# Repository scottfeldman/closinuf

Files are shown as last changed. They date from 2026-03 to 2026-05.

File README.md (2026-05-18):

# closinuf

**3D point scanner** — live 3D coordinates from four quadrature encoders on a Raspberry Pi, with a small web UI, foot‑switch capture, and FreeCAD‑friendly export.

<p align="center">
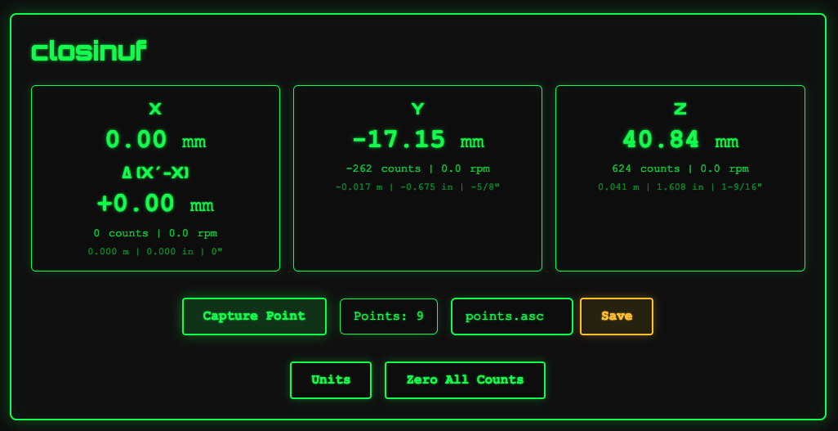
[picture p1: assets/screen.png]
closinuf 3D point scanner UI
  
</p>

## What it does

- Tracks **X**, **X'**, **Y**, **Z** from dedicated rotary encoders.  
- **Capture Point** in the browser or a **GPIO foot switch** appends the current **(X, Y, Z)** to a list (mm internally).
- **Save** downloads an **ASC** point cloud file, which can be imported into FreeCAD as a point cloud. 
- **Units** cycles mm → m → in → ft. **Zero** clears counts and points.
- **Short beep** on capture when audio output is available (speakers or HDMI).

## Hardware

See [HARDWARE.md](HARDWARE.md).

## Install on the Pi (`install.sh`)

1. On the Pi, clone the repository and enter the project directory:

   ```bash
   git clone https://github.com/scottfeldman/closinuf.git
   cd closinuf
   ```

2. Run the install script as root:

   ```bash
   sudo ./install.sh
   ```

3. Reboot if the installer prompts you to. 

What the script does:

- Enables **SPI** and relocates kernel CE pins off GPIO 8/7 (`dtoverlay=spi0-2cs,cs0_pin=12,cs1_pin=13`) in `/boot/firmware/config.txt`.
- Installs **`alsa-utils`** (`aplay` for capture beep) and **`golang-go`** if `go` is missing.
- Builds **`./closinuf`** in the repo.
- Adds the install user to **`spi`** and **`gpio`** groups (for local `go build` / debugging without the service).
- Installs **closinuf** **systemd** services: **`closinuf.service`** (app on :3000, runs as **root** for `/dev/mem` GPCLK, SPI, and GPIO), **`closinuf-browser.service`** (Chromium as install user)
- Prompts to **reboot** when SPI settings were added to `config.txt` (first install)

Useful commands:

```bash
sudo systemctl status closinuf closinuf-browser
sudo journalctl -u closinuf -f
```

## Manual run (development)

```bash
go build -o closinuf .
sudo ./closinuf
```

Open `http://127.0.0.1:3000`. Root is required for GPCLK setup (`/dev/mem`); the systemd service runs as root for the same reason.

## ASC export

One point per line: `X Y Z` in **millimeters** (space‑separated), suitable for FreeCAD point cloud import.

## Stack

Fiber, HTMX, gomponents, **LS7366R** counters over **SPI0**, **go-gpiocdev** (chip selects + foot switch).

## License

MIT — see [LICENSE](LICENSE).

## Author

Scott Feldman (2026)

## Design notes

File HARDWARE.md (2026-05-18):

# closinuf — Hardware Design

This document captures the **encoder counter board** that sits between the four
quadrature encoders and the Raspberry Pi. The board is a **Raspberry Pi 4 HAT**:
it stacks directly onto the Pi's 40‑pin GPIO header via `J1` and takes all of
its power from that header (3.3 V and 5 V). Counting is done in hardware by four
**LS7366R** single‑channel 32‑bit quadrature counter ICs (one encoder each), read by the Pi over **SPI0**.

The PCB sources for this design live in [`pcb/`](pcb/). This file is the
canonical reference for the schematic; if the two ever disagree, treat this
document as the spec.

---

## 1. System overview

```
                                                  +3.3V
                                                    │
                                                    ▼
   ┌──────────────┐   SPI0 + GPCLK0           ┌──────────────┐
   │              │   MOSI/MISO/SCLK ──┬─────►│ LS7366R  U1  │── Encoder X
   │   Raspberry  │   SS/ per chip      │      └──────────────┘
   │     Pi       │                     │      ┌──────────────┐
   │              │   GPIO4 (GPCLK0) ───┼─────►│ LS7366R  U2  │── Encoder X′
   │              │   (pin 7) ─ fCKi    │      └──────────────┘
   │              │   all four ICs       │      ┌──────────────┐
   │              │                     ├─────►│ LS7366R  U3  │── Encoder Y
   │              │                     │      └──────────────┘
   │              │                     │      ┌──────────────┐
   │              │                     └─────►│ LS7366R  U4  │── Encoder Z
   │  GPIO 26 ◄───┼── foot switch               └──────────────┘
   └──────────────┘
```

Four ICs total (one quadrature counter each). The Pi drives a shared **filter
clock** into every chip’s **fCKi** from **GPCLK0 on GPIO4** (header pin 7), and
periodically selects a chip, issues `READ_CNTR`, and reads four counter bytes
(32‑bit mode, `MDR1 = 0x00`).

### Counter range

Firmware uses **32‑bit** counter mode (`MDR1 = 0x00`). Signed headroom is
2^31 counts — far more than this application needs (600 PPR × 4 → 2400
counts/rev on a 50 mm wheel).

---

## 2. Bill of materials

| Ref | Qty | Part | Suggested MPN | KiCad footprint | Notes |
|---|-----|---|---|---|---|
| U1–U4 | 4 | **LS7366‑R** (DIP‑14, through‑hole) | `LS7366-R` | `LS7366R:DIP762W45P254L1917H533Q14` | Single‑channel 32‑bit quadrature counter with SPI (DIP package used on this board). |
| C1–C4 | 4 | 0.1 µF, X8R, disc, 50 V, ±10 % | TDK `FA18X8R1E104KNU00` | `Capacitor_THT:C_Disc_D3.8mm_W2.6mm_P2.50mm` | Decoupling, **at pin 14 (VDD)** of each chip. |
| C5 | 1 | 10 µF, X7R, disc, 10 V, ±10 % | TDK `FG14X7R1A106KRT00` | `Capacitor_THT:C_Disc_D5.0mm_W2.5mm_P2.50mm` | Bulk on the 3.3 V rail. |
| RN1–RN4 | 4 | 3× 4.7 kΩ bussed resistor network (SIP‑4) | Bourns `4604X-101-472LF` | `Resistor_THT:R_Array_SIP4` | Pull‑ups on every encoder A and B, plus the foot‑switch pull‑up. |
| J1 | 1 | 2×20 0.1″ socket | Samtec `SSW-120-01-T-D` (or any 2×20 2.54 mm socket) | `Connector_PinSocket_2.54mm:PinSocket_2x20_P2.54mm_Vertical` | Pi GPIO header connector. |
| J6 | 1 | 4‑pos PCB terminal block, 5 mm pitch, horizontal entry | Phoenix Contact `PT 1,5/ 4-5,0-H` (1935284) | `TerminalBlock_Phoenix:TerminalBlock_Phoenix_PT-1,5-4-5.0-H_1x04_P5.00mm_Horizontal` | Foot switch — only 2 of the 4 positions are wired (GPIO 26 + GND). |
| J2–J5 | 4 | 4‑pos PCB terminal block, 5 mm pitch, horizontal entry | Phoenix Contact `PT 1,5/ 4-5,0-H` (1935284) | `TerminalBlock_Phoenix:TerminalBlock_Phoenix_PT-1,5-4-5.0-H_1x04_P5.00mm_Horizontal` | Encoder cables (X, X′, Y, Z). Each carries A, B, **+5 V**, GND. |

---

## 3. Raspberry Pi pin assignment

40‑pin header. Only the pins relevant to this board are listed.

| Function | RPi GPIO (BCM) | Header pin |
|---|---|---:|
| SPI0 MOSI | GPIO 10 | 19 |
| SPI0 MISO | GPIO 9 | 21 |
| SPI0 SCLK | GPIO 11 | 23 |
| SS/ → U1 (encoder X) | GPIO 8 (CE0) | 24 |
| SS/ → U2 (encoder X′) | GPIO 7 (CE1) | 26 |
| SS/ → U3 (encoder Y) | GPIO 5 | 29 |
| SS/ → U4 (encoder Z) | GPIO 6 | 31 |
| **GPCLK0** → all **fCKi** | GPIO 4 | 7 |
| **Foot switch** (`J6`) | GPIO 26 | 37 |
| 3.3 V supply (LS7366R VDD) | — | 1, 17 |
| 5 V supply (encoder modules) | — | 2, 4 |
| GND | — | 6, 9, 14, 20, 25, 30, 34, 39 |

Notes:

- SPI1 is **not used**. All four LS7366R devices share **SPI0** MOSI, MISO, and
  SCLK; only **SS/** is unique per chip. Linux exposes **CE0** and **CE1** as
  GPIO 8 and 7; **U3** and **U4** use GPIO 5 and 6 as **manual** chip selects
  (drive high when idle, assert low during a transfer for that IC only).
- **Filter clock:** Tie **fCKi** (pin 2) on **U1–U4** together and connect to
  **GPIO4 / GPCLK0** (header pin 7). Configure the Pi to output a continuous
  square wave in the MHz range (see below). Per the datasheet, the internal
  filter clock `f_f` must satisfy `f_f >= 4 * f_QA`, where `f_QA` is the
  maximum frequency on encoder **A** in quadrature mode; at 3.3 V, `f_QA` is
  rated up to **4.5 MHz**, so **~9 MHz** (or higher) GPCLK is a comfortable
  choice.
- LS7366R devices, the pull‑up resistors, and the foot‑switch network all run
  from the Pi's **3.3 V** rail (header pins 1 / 17). The four encoder modules
  run from the Pi's **5 V** rail (header pins 2 / 4); their open‑collector
  A/B outputs are pulled up to 3.3 V at the LS7366R end so signal levels stay
  inside the chip's input range. Four LS7366Rs plus the pull‑ups still keep
  3.3 V load modest; encoder current is dominated by the encoder modules
  themselves (typically tens of mA each — check your encoder spec).

### `/boot/firmware/config.txt`

```ini
dtparam=spi=on
dtoverlay=spi0-2cs,cs0_pin=12,cs1_pin=13
```

`spi0-2cs` with **`cs0_pin` / `cs1_pin` moved off GPIO 8 and 7** is required: the
board uses those pins for manual **SS/** to the LS7366Rs. `install.sh` adds these
lines automatically.

Reboot after editing; `config.txt` is read only at boot. Verify with `ls /dev/spidev*`.

**GPCLK on GPIO4 (pin 7):** On **Raspberry Pi 4 (BCM2711)**, closinuf programs
GPCLK0 at **~9 MHz** from the **19.2 MHz oscillator** via `/dev/mem` in
`gpclk.go` at startup. The **`closinuf.service`** unit runs the app as
**root** so register access works without a separate setup script.

See [GPCLK / pinout](https://pinout.xyz/pinout/gpclk) and the LS7366R `fCKi`
filter requirements above.

On startup, `journalctl -u closinuf` should log `GPCLK0_CTL=… GPCLK0_DIV=0x00002222`.
Confirm ~9 MHz on header pin 7 with a scope if counts stay at zero.

---

## 4. LS7366R wiring (per chip)

Pinout (DIP‑14 / SOIC‑14, top view — per LSI/CSI datasheet):

```
                 LS7366R
               ┌────────────┐
      fCKO   1 ┤            ├ 14   VDD
      fCKi   2 ┤            ├ 13   CNT_EN
       VSS   3 ┤            ├ 12   A
       SS/   4 ┤            ├ 11   B
       SCK   5 ┤            ├ 10   INDEX/
      MISO   6 ┤            ├  9   DFLAG/
      MOSI   7 ┤            ├  8   LFLAG/
               └────────────┘
```

Wiring is **identical** for U1–U4 except **SS/** and which encoder A/B pair
connects to pins 12 / 11.

| Pin | Net |
|-----|-----|
| 1 | **fCKO** — **NC** (Pi drives **fCKi**; no crystal). |
| 2 | **fCKi** — **GPCLK0 / GPIO4** (header pin 7), **shared** by U1–U4. |
| 3 | GND (`VSS`) |
| 4 | **SS/** — chip select (GPIO 8 / 7 / 5 / 6 for U1–U4 respectively). |
| 5 | SPI0 SCLK (shared) |
| 6 | SPI0 MISO (shared) |
| 7 | SPI0 MOSI (shared) |
| 8 | `LFLAG/` — NC |
| 9 | `DFLAG/` — NC |
| 10  | `INDEX/` — **tie to 3.3 V** (index disabled in `MDR0`; active‑low pin). |
| 11  | Encoder **B**, **4.7 kΩ pull‑up to 3.3 V** |
| 12  | Encoder **A**, **4.7 kΩ pull‑up to 3.3 V** |
| 13  | `CNT_EN` — **tie to 3.3 V** (count enable; internal pull‑up exists). |
| 14  | **+3.3 V**, **0.1 µF to GND** at the pin |

### Encoder mapping

| Machine axis | Chip | Encoder A | Encoder B |
|---|---|---|---|
| X | U1 | pin 12 | pin 11 |
| X′ | U2 | pin 12 | pin 11 |
| Y | U3 | pin 12 | pin 11 |
| Z | U4 | pin 12 | pin 11 |

### SPI mode

Per the LS7366R datasheet (Figure 2 / setup notes):

- **SPI Mode 0** (CPOL = 0, CPHA = 0): SCK idles low.
- MSB first on MOSI and MISO.
- Framed by **SS/** low → … transfer … → **SS/** high; only one device’s **SS/**
  must be low at a time so **MISO** can be shared.
- At **3.3 V**, the datasheet specifies **120 ns** minimum SCK high and low times,
  implying roughly **≤ ~4 MHz** SCK unless you verify timing at your supply and
  temperature.

### Register configuration (firmware)

Configure **each** of U1–U4 the same way (`ls7366.go`):

| Register | Value  | Meaning |
|---|---|---|
| `MDR0` | `0x03` | x4 quadrature, free‑running, index disabled, filter divide = 1 |
| `MDR1` | `0x00` | 32‑bit counter mode, counting enabled |

Instruction bytes:

```
WRITE_MDR0 = 0x88
WRITE_MDR1 = 0x90
READ_MDR0  = 0x48
READ_MDR1  = 0x50
CLR_CNTR   = 0x20
READ_CNTR  = 0x60   ; latches CNTR → OTR, then clocks out OTR on MISO
```

Initialization **per chip**: `WRITE_MDR1`, `WRITE_MDR0`, `CLR_CNTR`. Startup runs
**`verifyChip`**: `READ_MDR1` / `READ_MDR0` must match, then `READ_CNTR` must be 0.

Periodic read: `READ_CNTR` plus four data bytes on MISO (32‑bit mode).

---

## 5. Encoders

Each encoder is connected via a 4‑pin cable: **A**, **B**, **+5 V**, **GND**,
landed on a 4‑position screw terminal (`J2` = X, `J3` = X′, `J4` = Y, `J5` = Z).
The encoder modules themselves run from the Pi's **+5 V** rail (header pin 2 or 4);
their A/B outputs are NPN open‑collector and are pulled up to **3.3 V** at the
LS7366R end by `RN1`–`RN4`, so the signal seen by the chip is a clean 3.3 V CMOS
level — never above the LS7366R's `VDD`.

Encoder Z (index) is not used; each chip's **`INDEX/`** pin is tied to **3.3 V**
and index is disabled in `MDR0`. If you ever want homing on index, lift the
3.3 V tie, add a pull‑up, route the encoder index to **`INDEX/`**, and set the
`MDR0` index field to the desired mode (load / reset / load OTR).

Per the firmware defaults (`main.go`): **32‑bit** counter mode (`MDR1 = 0x00`),
600 PPR, x4 quadrature → 2400 counts/rev; 50 mm wheel diameter, ≈157.08 mm/rev,
≈0.0654 mm/count.

The LS7366R's max quadrature input rate at 3.3 V is **4.5 MHz** on A/B (with
`fCKi` and filter settings that meet `f_f >= 4 * f_QA`), which at 600 PPR is
still far beyond anything this machine produces.

---

## 6. Foot switch

Connector **J6** (4‑pos screw terminal, 2 of the 4 positions wired):

| Net | Connection |
|---|---|
| Switch.1 | GPIO 26 (header pin 37), 4.7 kΩ pull‑up (one element of `RN1`–`RN4`) to 3.3 V |
| Switch.2 | GND (header pin 39) |

Normally open, momentary. Software treats falling edge as "capture point",
with debounce and ≥500 ms minimum spacing in firmware.

---

## 7. Detailed wiring diagram

```
                           Raspberry Pi 40-pin header (J1)
   ┌───────────────────────────────────────────────────────────────────┐
   │ +3V3 (pin 1, 17) ──────────────► +3V3 rail ────► U1..U4 pin 14
   │                                                └─► all 4k7 pull-ups (RN1..RN4)
   │                                                └─► CNT_EN (pin 13), INDEX/ (pin 10)
   │ +5V  (pin 2, 4)  ──────────────► +5V rail  ────► J2..J5 (encoder modules)
   │ GND  (pin 6,9,...)─────────────► GND rail  ────► U1..U4 pin 3 (VSS)
   │                                                └─► J6 foot switch
   │                                                └─► J2..J5 encoder GND
   │
   │ ── SPI0 ─────────────────────────────────────────────────────────── │
   │ GPIO10 (pin 19) MOSI ─────►  U1..U4 pin 7
   │ GPIO9  (pin 21) MISO ◄─────  U1..U4 pin 6
   │ GPIO11 (pin 23) SCLK ─────►  U1..U4 pin 5
   │ GPIO8  (pin 24) CE0  ─────►  U1 pin 4   (encoder X)
   │ GPIO7  (pin 26) CE1  ─────►  U2 pin 4   (encoder X′)
   │ GPIO5  (pin 29)        ───►  U3 pin 4   (encoder Y)   manual SS/
   │ GPIO6  (pin 31)        ───►  U4 pin 4   (encoder Z)   manual SS/
   │
   │ GPIO4  (pin 7)  GPCLK0 ───►  U1..U4 pin 2 (fCKi), shared
   │
   │ GPIO26 (pin 37) ◄── J6 foot switch ── GND;  4.7kΩ pull-up via RN1..RN4 to +3V3
   └────────────────────────────────────────────────────────────────────┘

  Each LS7366R (Ux): one encoder; pin 1 (fCKO) NC; pin 2 (fCKi) = shared GPCLK.

                          +3.3 V
                            │
                ┌───────────┴───────────┐
                │                       │
   Encoder.A  ──┴──► pin 12   +3.3V ────► pin 10 (INDEX/)
   Encoder.B  ─────► pin 11   +3.3V ────► pin 13 (CNT_EN)
                            +3.3V ──┬─────── pin 14 (VDD)
                                    │
                                 [0.1µF]    ◄── decoupling (C1..C4), at pin 14
                                    │
                                   GND
                                    │
                            GND ────┴─────── pin 3  (VSS)

   Pin 4  (SS/)   : GPIO 8 / 7 / 5 / 6 for U1..U4
   Pin 5  (SCK)   : SPI0 SCLK (shared)
   Pin 6  (MISO)  : SPI0 MISO (shared)
   Pin 7  (MOSI)  : SPI0 MOSI (shared)
   Pin 8  (LFLAG/): NC
   Pin 9  (DFLAG/): NC

  +3V3 rail also carries C5 (10 µF bulk) to GND, placed near J1.
```

---

## 8. Layout / signal‑integrity notes

- **Decoupling first.** Each LS7366R gets its own 0.1 µF directly across
  pins 14 ↔ 3 with the shortest possible loop. One 10 µF bulk cap somewhere
  on the 3.3 V rail is enough.
- **fCKi routing.** Keep the **GPCLK** net short and matched to all four **fCKi**
  inputs; optional series damping (e.g. 22 Ω) at the source can calm reflections.
- **Encoder traces.** Pull‑ups should sit near the LS7366R end (the receiver),
  not at the connector — that gives the cleanest edges into the on‑chip filter.
- **Ground.** Single ground plane. Star ground back to the Pi via the header's
  GND pins; don't share encoder return current with the Pi power return if
  encoder cables are long.
- **ESD.** Encoder inputs go to a connector and out into the world; if you
  expect rough handling, add a TVS or 5 V Zener on each A/B line.

## 9. Reference

- LS7366R datasheet: <https://lsicsi.com/wp-content/uploads/2021/06/LS7366R.pdf>
- BCM2711 / RPi GPIO reference: <https://www.raspberrypi.com/documentation/computers/raspberry-pi.html#gpio>

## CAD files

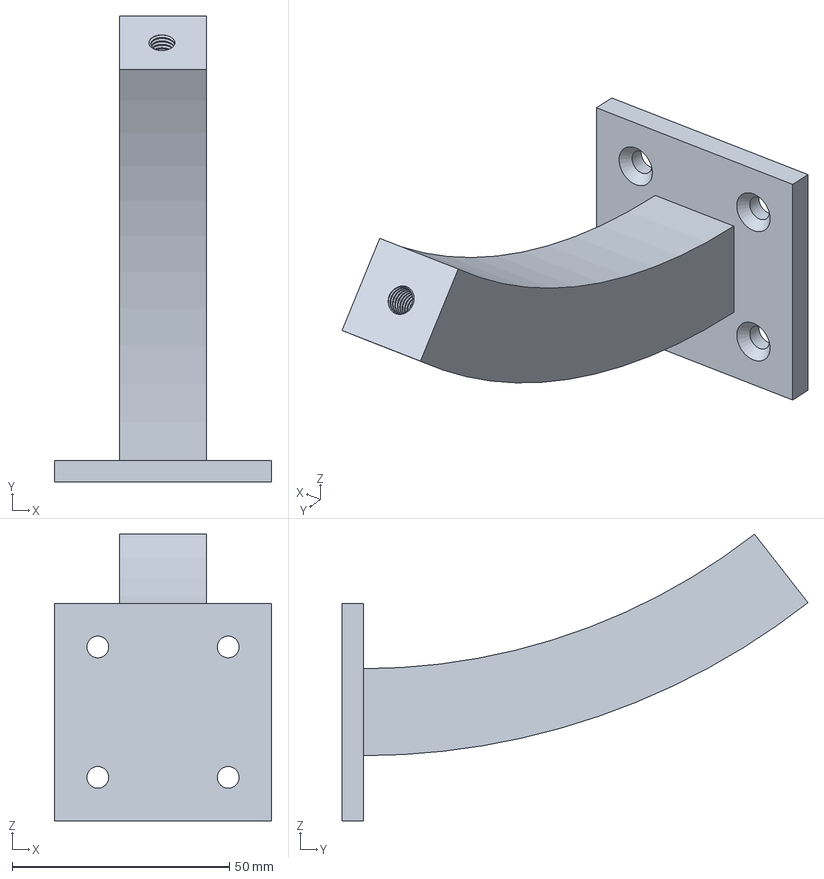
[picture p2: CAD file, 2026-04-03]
cad/rpi mount base.FCStd
50.0 x 107.2 x 66.0 mm

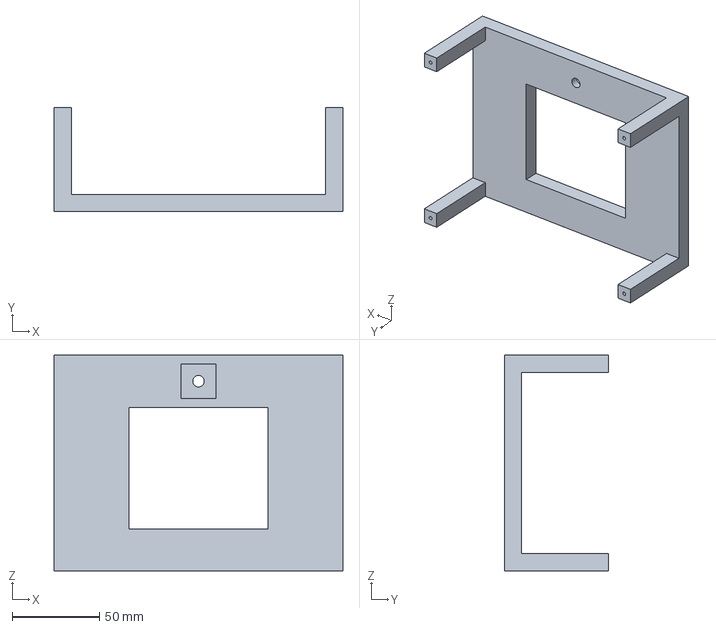
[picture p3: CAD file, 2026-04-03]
cad/rpi mount.FCStd
166.0 x 60.0 x 124.0 mm

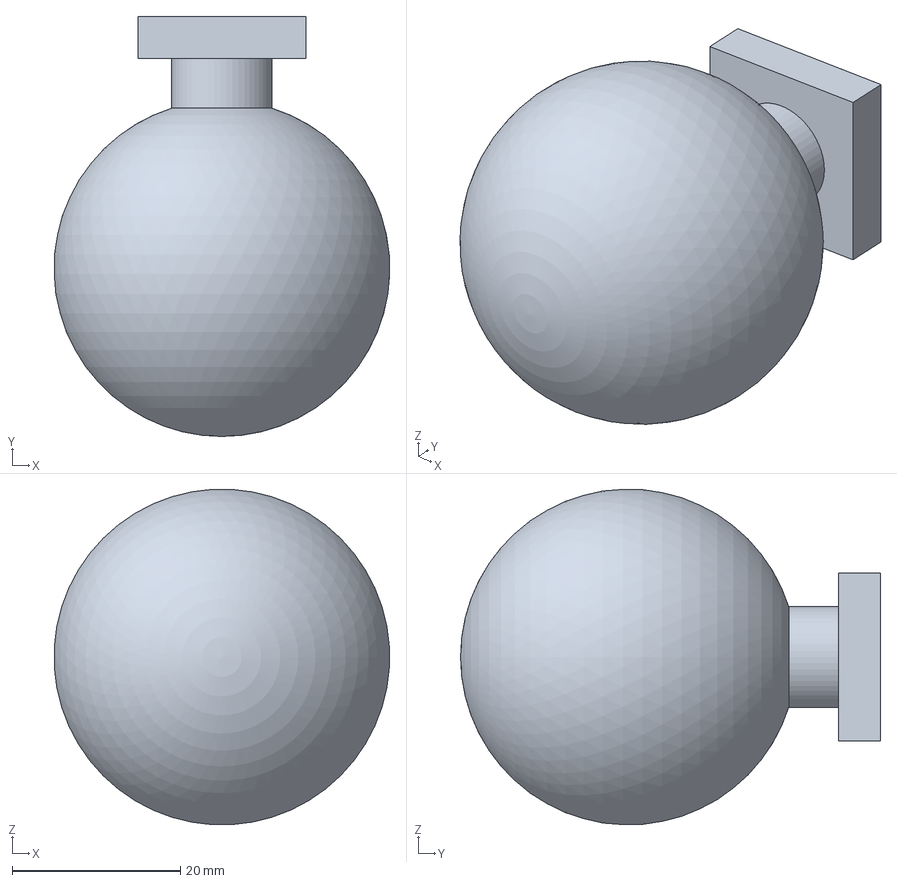
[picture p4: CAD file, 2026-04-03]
cad/rpi mount ball.FCStd
39.9 x 50.0 x 39.9 mm

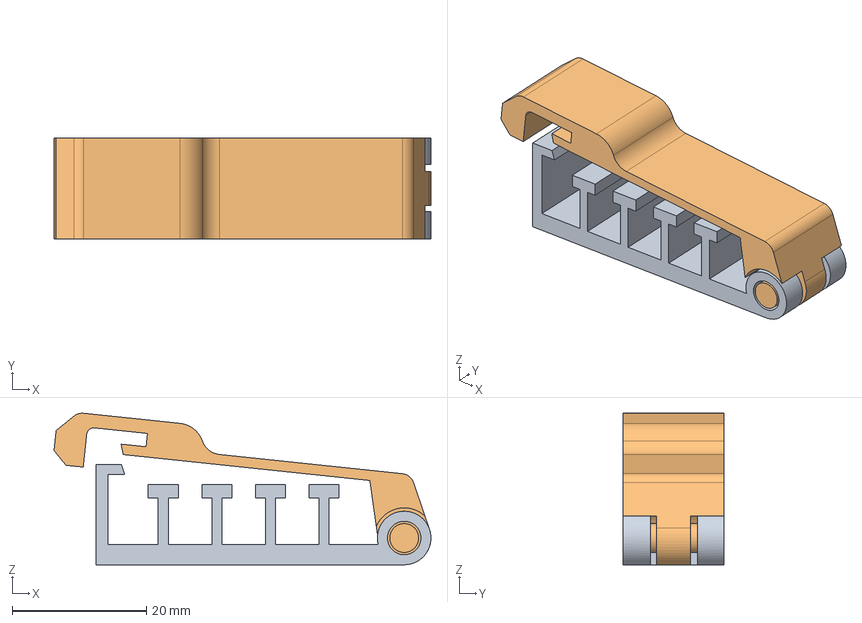
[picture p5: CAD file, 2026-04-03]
cad/cable comb x5.FCStd
56.2 x 15.0 x 22.6 mm

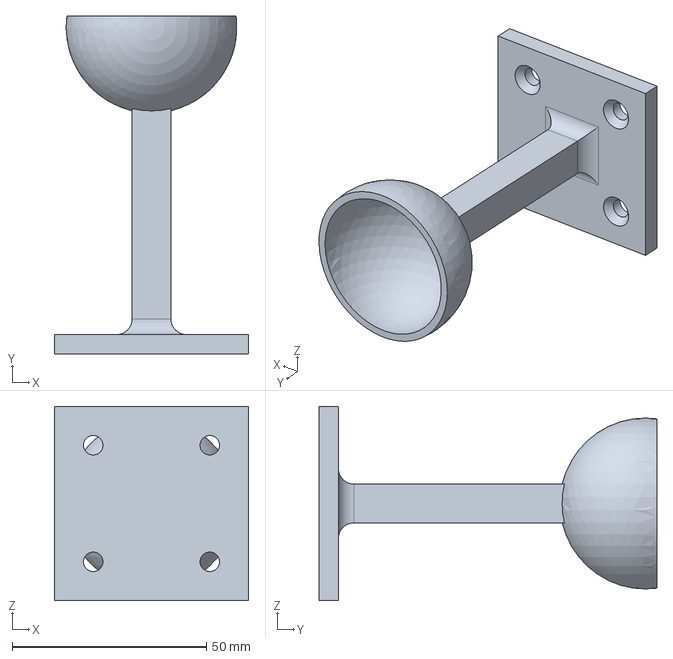
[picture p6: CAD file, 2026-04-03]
cad/rpi mount socket.FCStd
50.0 x 87.0 x 50.0 mm

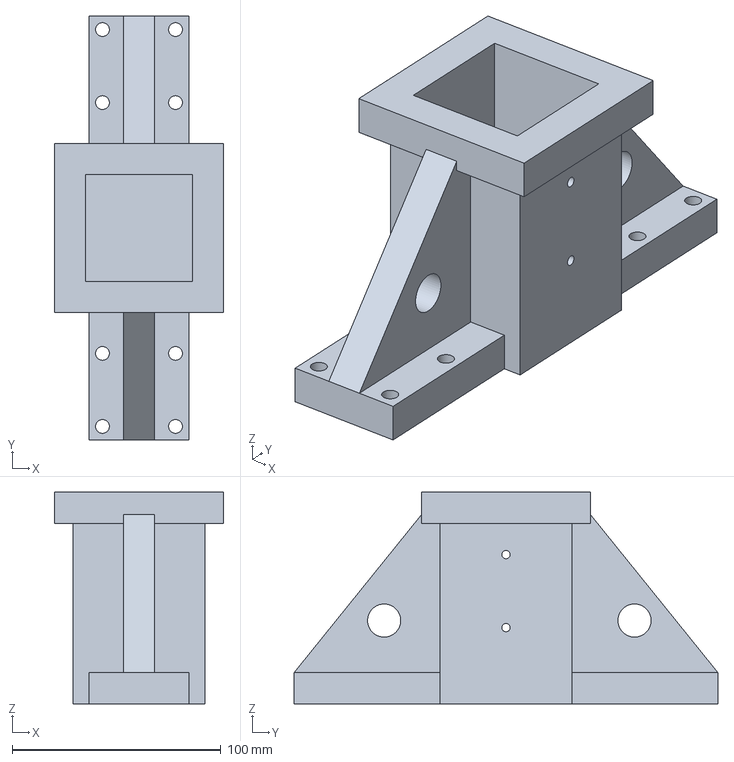
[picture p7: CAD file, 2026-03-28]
cad/2x upright.FCStd
81.0 x 203.2 x 101.6 mm

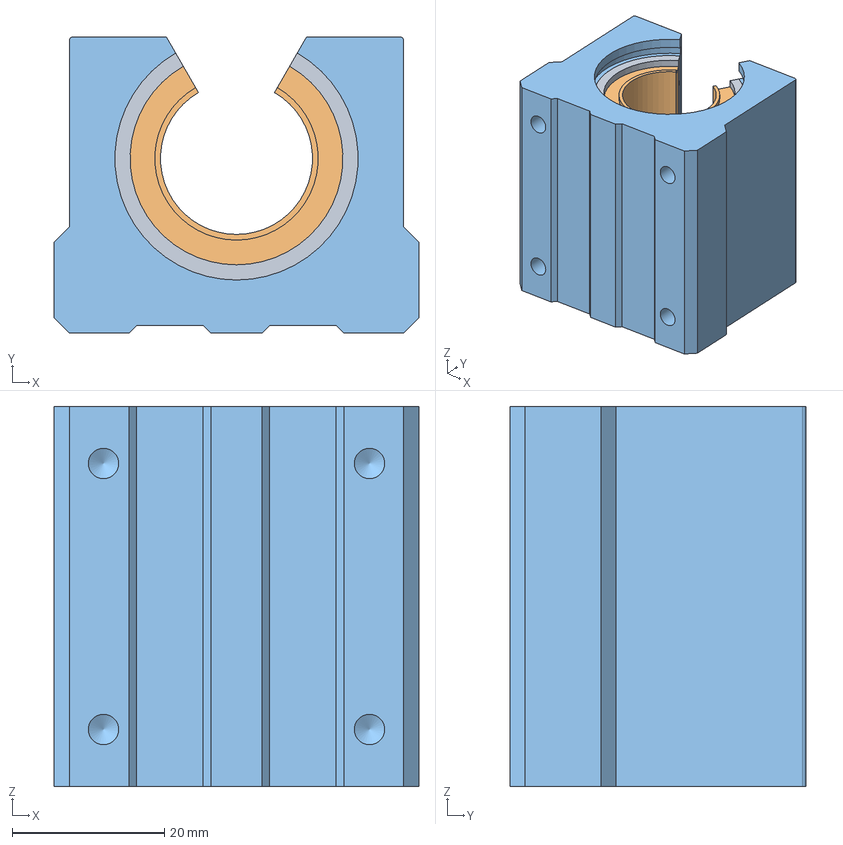
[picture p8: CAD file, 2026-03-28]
cad/SBR20UU.FCStd
48.0 x 39.0 x 50.0 mm
LM20UUOP
LM20UUOP001
TBR20UU
retaining ring001

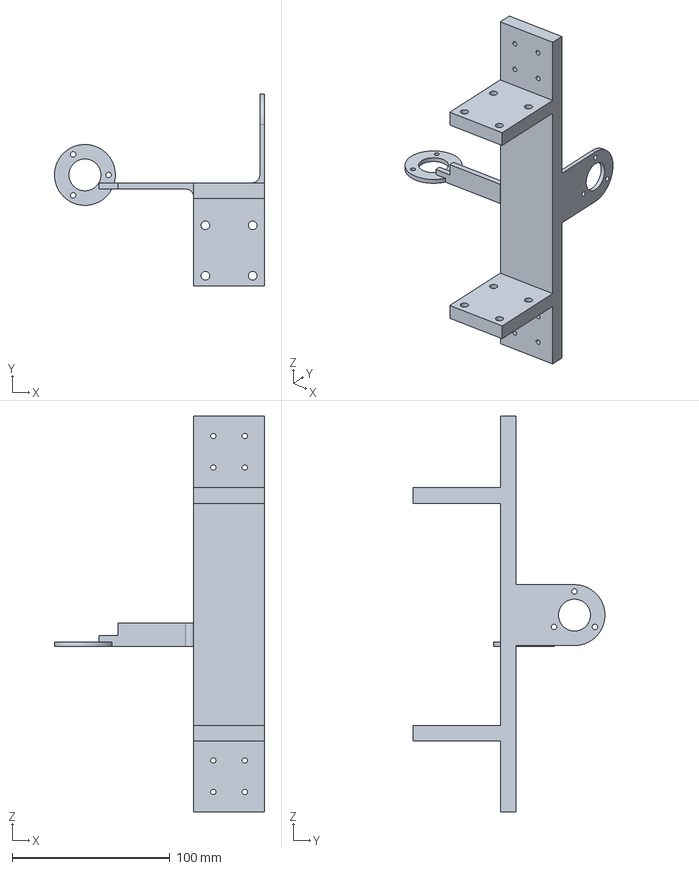
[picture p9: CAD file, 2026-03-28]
cad/y mount rear.FCStd
133.3 x 121.9 x 251.4 mm

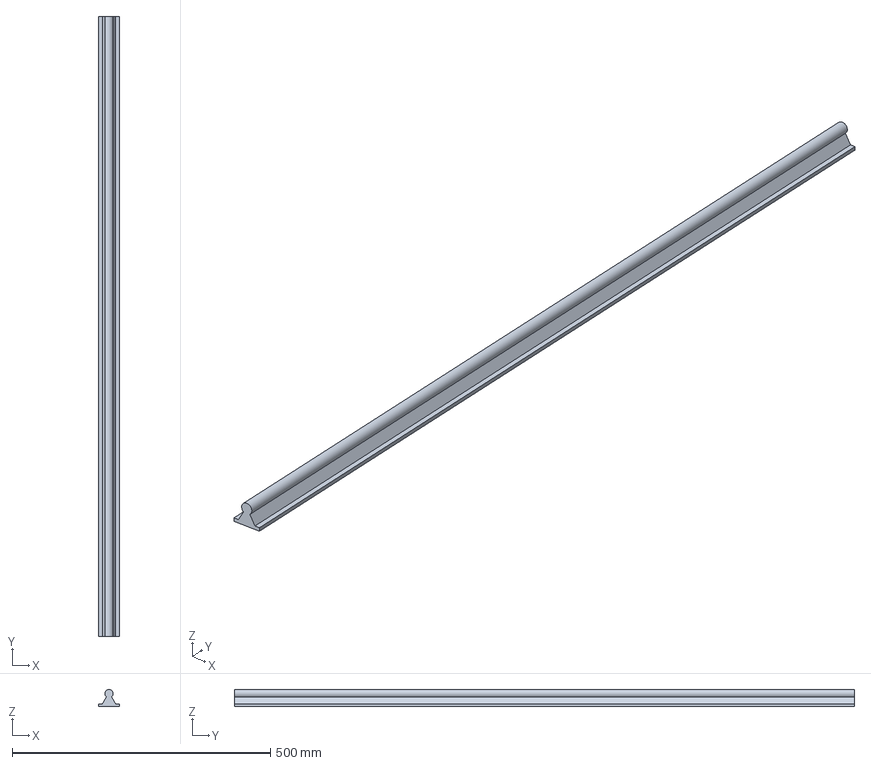
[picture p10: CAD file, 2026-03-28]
cad/SBR16 rail.FCStd
40.0 x 1200.0 x 33.0 mm

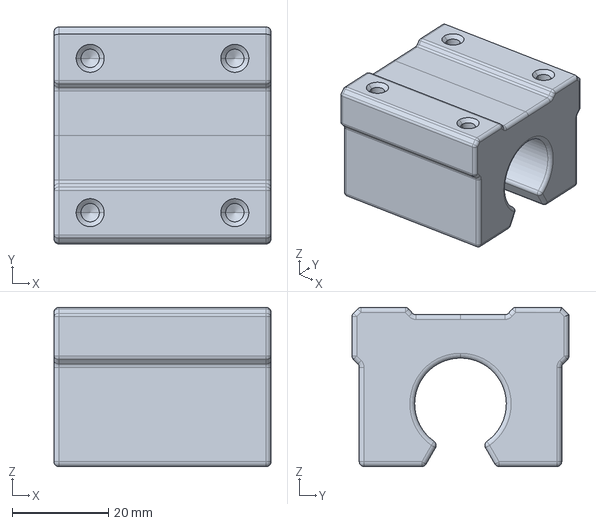
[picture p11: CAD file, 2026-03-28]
cad/SBR16UU.FCStd
45.0 x 45.0 x 33.0 mm

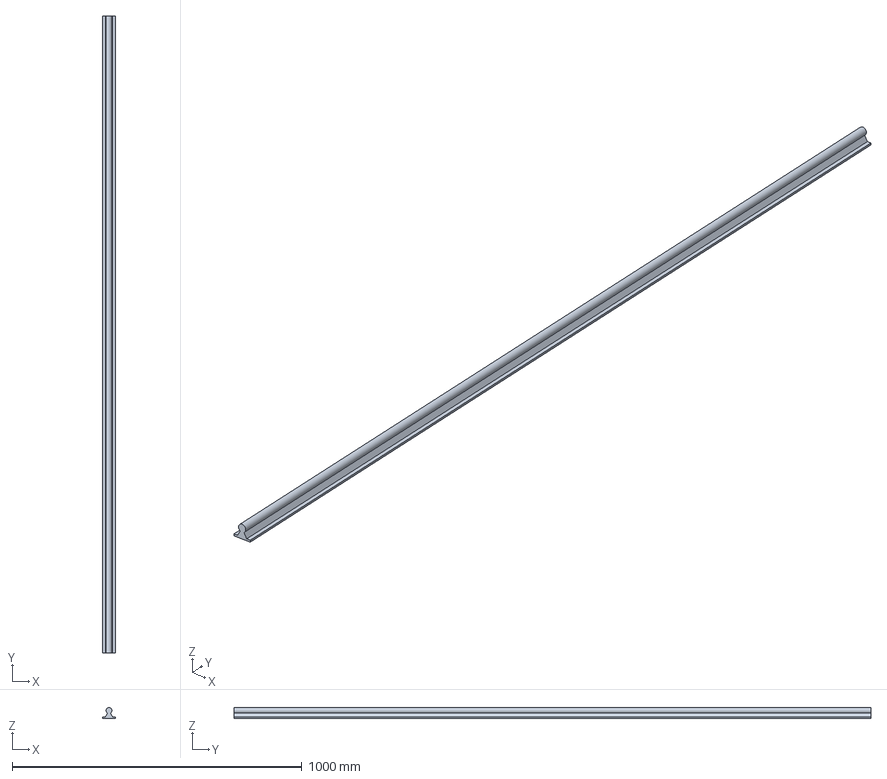
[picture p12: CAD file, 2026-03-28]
cad/SBR20 2200mm rail.FCStd
45.0 x 2200.0 x 37.0 mm

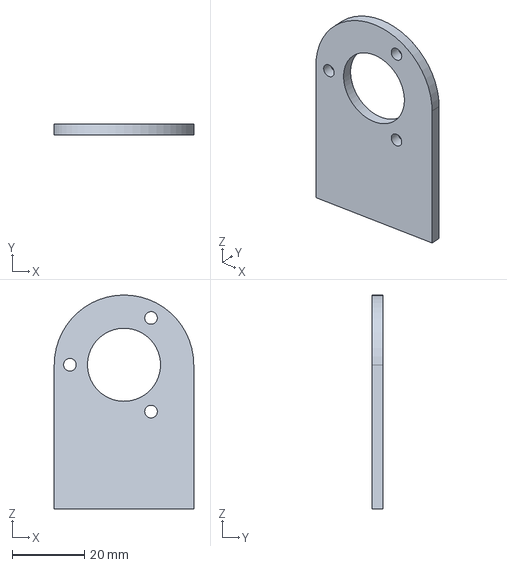
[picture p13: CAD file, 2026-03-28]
cad/z encoder mount.FCStd
38.7 x 3.00 x 59.4 mm

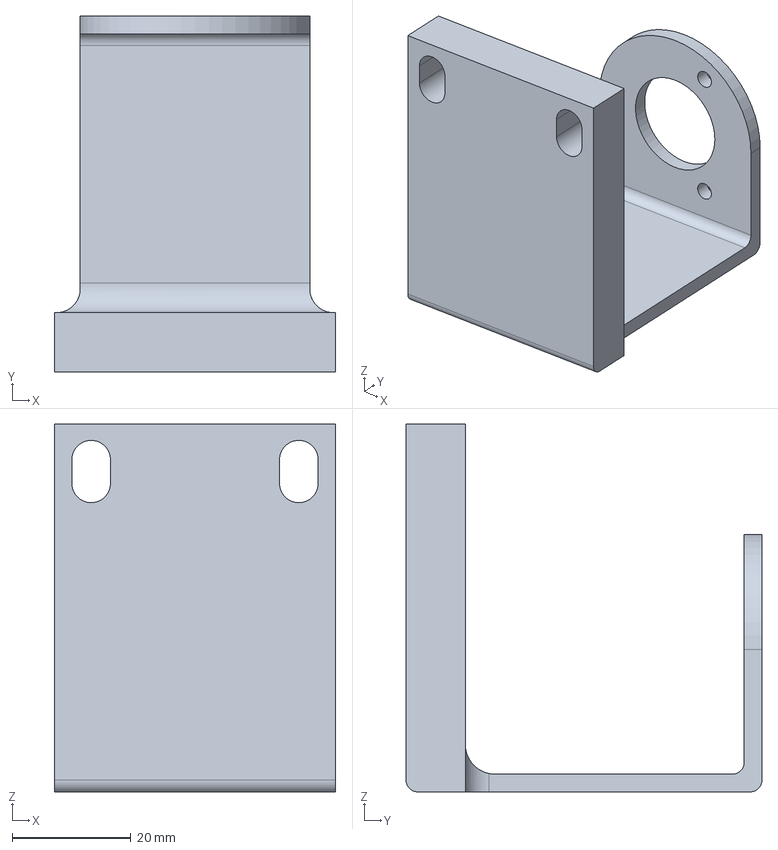
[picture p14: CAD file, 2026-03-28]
cad/encoder mount.FCStd
47.4 x 60.0 x 62.0 mm

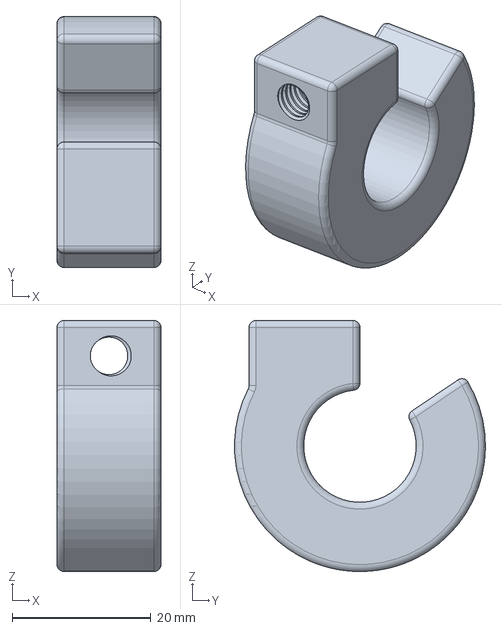
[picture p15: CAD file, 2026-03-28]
cad/SBR16 rail stop.FCStd
15.0 x 36.2 x 36.2 mm

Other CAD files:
cad/closinuf.FCStd
cad/encoder wheel.FCStd
cad/rotary encoder 600 ppr.FCStd
cad/SBR20 rail stop.FCStd
cad/2x2 corner.FCStd
cad/2x2x0.125 tubing.FCStd
cad/x carrier.FCStd

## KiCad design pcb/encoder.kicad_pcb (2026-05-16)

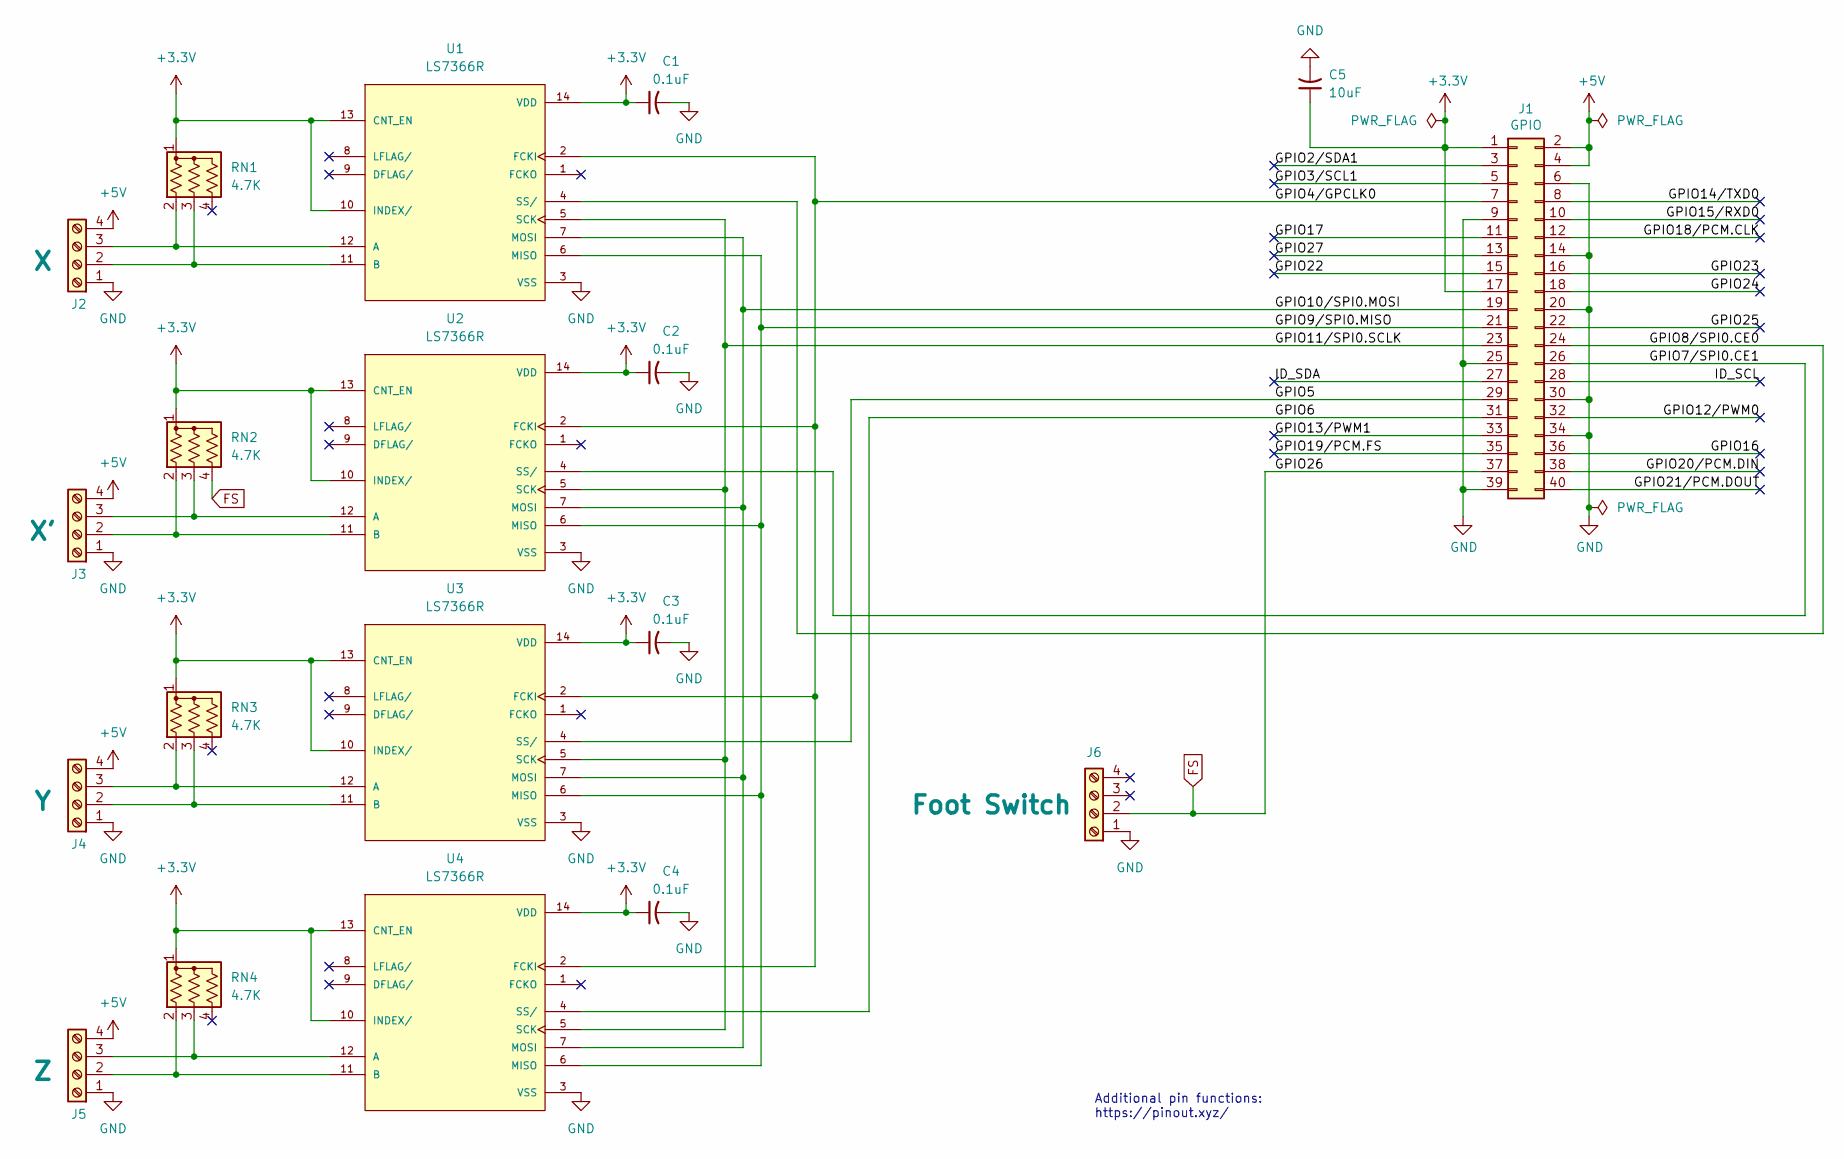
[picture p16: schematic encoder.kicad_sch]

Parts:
C1, C2, C3, C4: 0.1uF; C_Disc_D3.8mm_W2.6mm_P2.50mm; MPN FA18X8R1E104KNU00
C5: 10uF; C_Disc_D5.0mm_W2.5mm_P2.50mm; MPN FG14X7R1A106KRT00
J1: GPIO; PinSocket_2x20_P2.54mm_Vertical
J2: X; TerminalBlock_Phoenix_PT-1,5-4-5.0-H_1x04_P5.00mm_Horizontal
J3: X'; TerminalBlock_Phoenix_PT-1,5-4-5.0-H_1x04_P5.00mm_Horizontal
J4: Y; TerminalBlock_Phoenix_PT-1,5-4-5.0-H_1x04_P5.00mm_Horizontal
J5: Z; TerminalBlock_Phoenix_PT-1,5-4-5.0-H_1x04_P5.00mm_Horizontal
J6: Foot Switch; TerminalBlock_Phoenix_PT-1,5-4-5.0-H_1x04_P5.00mm_Horizontal
RN1, RN2, RN3, RN4: 4.7K; R_Array_SIP4; MPN 4604X-101-472LF
U1, U2, U3, U4: LS7366R; DIP762W45P254L1917H533Q14; PARTREV June 2014

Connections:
+3.3V: C1.1, C2.1, C3.1, C4.1, C5.1, J1.1, J1.17, RN1.1 (common), RN2.1 (common), RN3.1 (common), RN4.1 (common), U1.10 (INDEX/), U1.13 (CNT_EN), U1.14 (VDD), U2.10 (INDEX/), U2.13 (CNT_EN), U2.14 (VDD), U3.10 (INDEX/), U3.13 (CNT_EN), U3.14 (VDD), U4.10 (INDEX/), U4.13 (CNT_EN), U4.14 (VDD)
+5V: J1.2, J1.4, J2.4, J3.4, J4.4, J5.4
/GPIO2/SDA1: J1.3
/GPIO3/SCL1: J1.5
/GPIO4/GPCLK0: J1.7, U1.2 (FCKI), U2.2 (FCKI), U3.2 (FCKI), U4.2 (FCKI)
/GPIO5: J1.29, U3.4 (SS/)
/GPIO6: J1.31, U4.4 (SS/)
/GPIO7/SPI0.CE1: J1.26, U2.4 (SS/)
/GPIO8/SPI0.CE0: J1.24, U1.4 (SS/)
/GPIO9/SPI0.MISO: J1.21, U1.6 (MISO), U2.6 (MISO), U3.6 (MISO), U4.6 (MISO)
/GPIO10/SPI0.MOSI: J1.19, U1.7 (MOSI), U2.7 (MOSI), U3.7 (MOSI), U4.7 (MOSI)
/GPIO11/SPI0.SCLK: J1.23, U1.5 (SCK), U2.5 (SCK), U3.5 (SCK), U4.5 (SCK)
/GPIO12/PWM0: J1.32
/GPIO13/PWM1: J1.33
/GPIO14/TXD0: J1.8
/GPIO15/RXD0: J1.10
/GPIO16: J1.36
/GPIO17: J1.11
/GPIO18/PCM.CLK: J1.12
/GPIO19/PCM.FS: J1.35
/GPIO20/PCM.DIN: J1.38
/GPIO21/PCM.DOUT: J1.40
/GPIO22: J1.15
/GPIO23: J1.16
/GPIO24: J1.18
/GPIO25: J1.22
/GPIO27: J1.13
/ID_SCL: J1.28
/ID_SDA: J1.27
FS: J1.37, J6.2, RN2.4 (R3)
GND: C1.2, C2.2, C3.2, C4.2, C5.2, J1.6, J1.9, J1.14, J1.20, J1.25, J1.30, J1.34, J1.39, J2.1, J3.1, J4.1, J5.1, J6.1, U1.3 (VSS), U2.3 (VSS), U3.3 (VSS), U4.3 (VSS)
unnamed: J2.2, RN1.3 (R2), U1.11 (B)
unnamed: J2.3, RN1.2 (R1), U1.12 (A)
unnamed: J3.2, RN2.2 (R1), U2.11 (B)
unnamed: J3.3, RN2.3 (R2), U2.12 (A)
unnamed: J4.2, RN3.3 (R2), U3.11 (B)
unnamed: J4.3, RN3.2 (R1), U3.12 (A)
unnamed: J5.2, RN4.2 (R1), U4.11 (B)
unnamed: J5.3, RN4.3 (R2), U4.12 (A)

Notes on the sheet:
Additional pin functions: https://pinout.xyz/

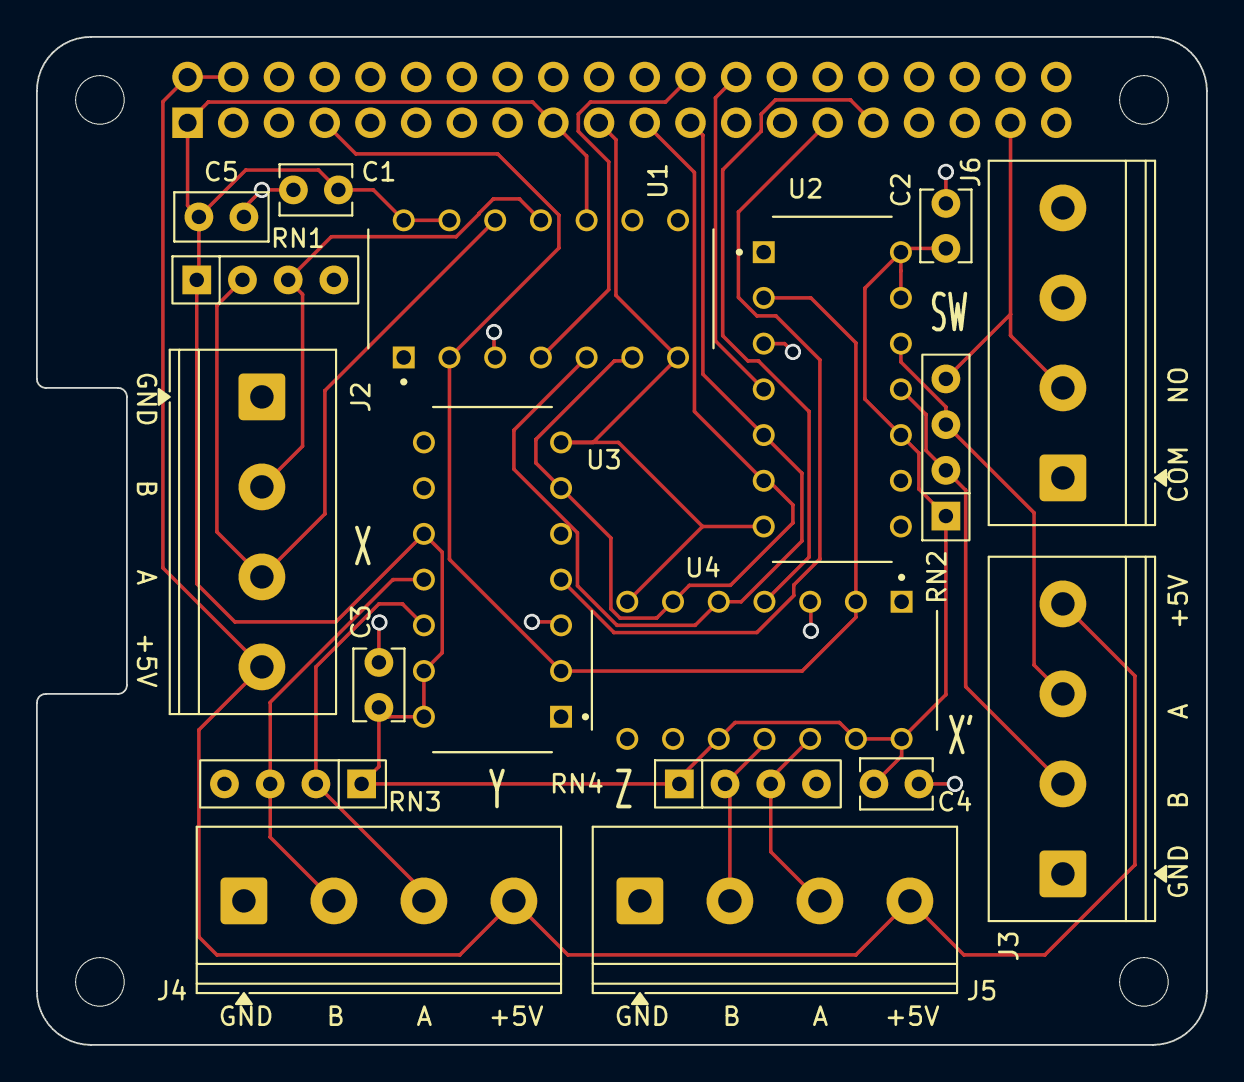
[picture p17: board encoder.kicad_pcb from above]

Board: 2 copper layers, 65.0 x 56.0 mm, 23 parts (1 on the bottom side), 20 nets.

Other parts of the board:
MH1, MH2, MH3, MH4: MountingHole_2.7mm_M2.5

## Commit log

2026-01-16 add encoder reader
2026-01-22 working on puxh button
2026-01-22 fix wrong wiring on push button
2026-01-28 first checkin
    [2x2 corner.FCStd, 2x2x0.125 tubing.FCStd, SBR20 2200mm rail.FCStd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]
2026-01-30 update 2x2 corners
    [2x2 corner.FCStd, 2x2 corner.step, closinuf.FCStd]
2026-01-30 update PCB to add two more terminals
    [2x2 corner.FCStd, closinuf.FCStd, encoders.kicad_pcb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]
2026-01-30 add gerber file
    [encoders-B_Cu.gbl, encoders-B_Mask.gbs, encoders-B_Paste.gbp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]
2026-02-06 final corner/uprights
    [2x upright.FCStd, 2x upright.step, 2x2x0.125 tubing.FCStd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]
2026-02-15 add X' and update GPIOs to match latest PCB
2026-03-19 update/add more CAD parts
    [2x upright.FCStd, 2x upright.step, 2x2 corner.step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]
2026-03-28 more parts
    [2x upright.FCStd, 2x2x0.125 tubing.FCStd, SBR16 rail stop.FCStd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]
2026-04-01 more 3d parts
    [rpi mount ball.FCStd, rpi mount base.FCStd, rpi mount socket.FCStd]
2026-04-27 updated schematic using ls7466s
    [encoders.kicad_pcb, encoders.kicad_sch]
2026-04-27 remove unnecessary files from pcb/
    [encoders-B_Cu.gbl, encoders-B_Mask.gbs, encoders-B_Paste.gbp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]
2026-04-27 update .gitignore to ignore all but the most importatnt pcb/ files
2026-04-27 add footprints
    [encoders.kicad_sch]
2026-04-27 redo schematic
    [encoder.kicad_pcb, encoder.kicad_sch, encoders.kicad_sch]
2026-04-28 assign footprints
    [encoder.kicad_sch]
2026-04-28 snapshot...working on routing
    [encoder.kicad_pcb, encoder.kicad_sch]
2026-04-29 route with ls74633 chips
    [encoder.kicad_pcb, encoder.kicad_sch]
2026-04-29 update hardware.md to match schematic
    [encoder.kicad_pcb]
2026-05-02 update BOM
    [encoder.kicad_pcb, encoder.kicad_sch]
2026-05-07 move to thru-hole resistors/caps to save costs
    [encoder.kicad_pcb, encoder.kicad_sch]
2026-05-07 sync hardware.md with BOM from schematic
    [encoder.kicad_sch]
2026-05-16 update to kicad version 10.0.3
    [encoder.kicad_pcb, encoder.kicad_sch]
